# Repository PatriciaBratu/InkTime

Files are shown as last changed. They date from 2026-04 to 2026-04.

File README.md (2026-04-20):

README  
  
┌─────────────────────────────────────────────────────────────┐  
│                        POWER SUPPLY                         │  
│                                                             │  
│  Li-Po Battery (3.7V)                                       │  
│       │                                                     │  
│       ▼                                                     │  
│  BQ25180 (Charger IC)  ◄──── USB Type-C (J4)                │  
│       │                                                     │  
│       ▼                                                     │  
│  RT6160A (Buck-Boost)  ──► 3.3V stable output               │  
│       │                                                     │  
│  MAX17048 (Fuel Gauge) ──► I2C ──► nRF52840                 │  
└─────────────────────────────────────────────────────────────┘  
  
┌─────────────────────────────────────────────────────────────┐  
│                    PROCESSING UNIT                          │  
│                                                             │  
│              nRF52840 (ARM Cortex-M4F)                      │  
│        ┌──────────────┴──────────────┐                      │  
│        │                             │                      │  
│      SPI bus                       I2C bus                  │  
│        │                             │                      │  
│  e-Paper Display               ┌─────┴──────┐               │  
│  (1.54" GDEW0154)              │            │               │  
│                            BMA421       DRV2605YZFR         │  
│                           (Accel.)    (Haptic Driver)       │  
└─────────────────────────────────────────────────────────────┘  

Descrierea Funcționalității Hardware

Sistemul InkTime v6 este optimizat pentru autonomie maximă, utilizând componente de ultimă generație.  
## Microcontroller — nRF52840  
Utilizăm SoC-ul **nRF52840** (U1) care integrează un nucleu ARM Cortex-M4F la 64 MHz. Acesta gestionează stiva **Bluetooth Low Energy (BLE)** și coordonează perifericele prin interfețele SPI și I2C.  
  
Sistemul de Alimentare (Power Tree)  
**BQ25180 (IC1):** IC de încărcare liniară cu managementul căii de alimentare (Power Path).  
**MAX17048 (U3):** Fuel Gauge care utilizează algoritmul ModelGauge pentru monitorizarea precisă a stării de încărcare a bateriei via I2C, fără a necesita calibrare manuală.  
**RT6160A (IC9):** Regulator Buck-Boost care menține o ieșire stabilă de 3.3V pe tot parcursul ciclului de descărcare al bateriei (4.2V - 3.0V).  
  
## Afișaj e-Paper (1.54")  
Utilizăm panoul **GDEW0154** conectat prin J1. Consumul este zero între actualizări. Schema include un **E-Paper Drive Circuit** cu inductorul **L5 (5.6uH)** și diode Schottky **MBR0530** (D2, D4, D5) pentru generarea tensiunilor de refresh. Alimentarea este controlată de un MOSFET P-Channel (Q1) pentru a elimina curentul de scurgere în standby.  
  
Senzor de Mișcare și Haptics  
**BMA421 (IC3):** Accelerometru triaxial ultra-low-power utilizat pentru funcția de *tilt-to-wake* și pedometru.  
**DRV2605YZFR (IC2):** Driver haptic specializat care controlează motorul de vibrații, oferind peste 100 de efecte tactile pre-programate via I2C.  
  
## Configurația Pinilor nRF52840  
Maparea pinilor a fost optimizată pentru rutarea pe 4 straturi a PCB-ului:  
+1  

| Semnal | Pin nRF52 | Direcție | Descriere |
| --- | --- | --- | --- |
| EPD_SCK  | P0.28 | Output | Clock SPI pentru afișaj |
| EPD_MOSI | P0.29 | Output | Date imagine către afișaj  |
| EPD_CS | P0.30 | Output | Chip Select Display |
| EPD_DC | P0.31 | Output | Data/Command selector |
| I2C_SDA  | P0.26 | Bidirecțional | Magistrală date senzori |
| I2C_SCL  | P0.27 | Output | Magistrală clock senzori |
| EPD_PWR  | P0.13 | Output | Control alimentare E-Paper |
| SW_UP | P1.00 | Input | Buton Navigare Sus |
| SW_ENT | P1.01 | Input | Buton Selecție |
| SW_DN | P1.02 | Input | Buton Navigare Jos |

## Calcule Consum Energie (Estimativ)  
* **Deep Sleep (System ON):** ~3.2 μA.  
* **I2C Polling (Senzori):** ~150 μA.  
* **E-Paper Refresh:** ~8 mA (timp de 2 secunde).  
* **Baterie 250 mAh:** Autonomie estimată de **35 zile** (cu 10 refresh-uri/zi și Bluetooth activ).  
## Integrare Mecanică  
Designul a fost validat în Fusion 360 prin analiză de coliziune între baterie și componentele înalte (inductorul L5 și conectorul USB-C). Carcasa WearAwareNewCase oferă o protecție IP67 simbolică.

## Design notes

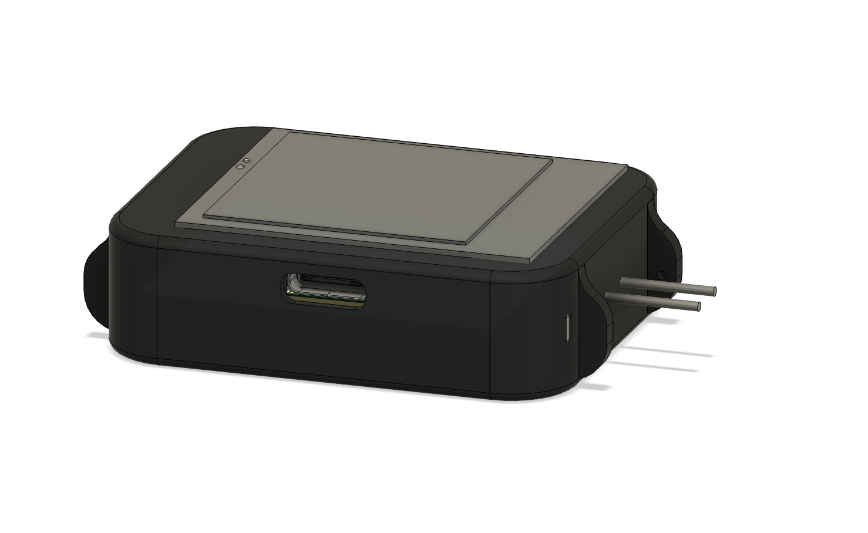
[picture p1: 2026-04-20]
Images/Screenshot 2026-04-20 at 17.06.30.png

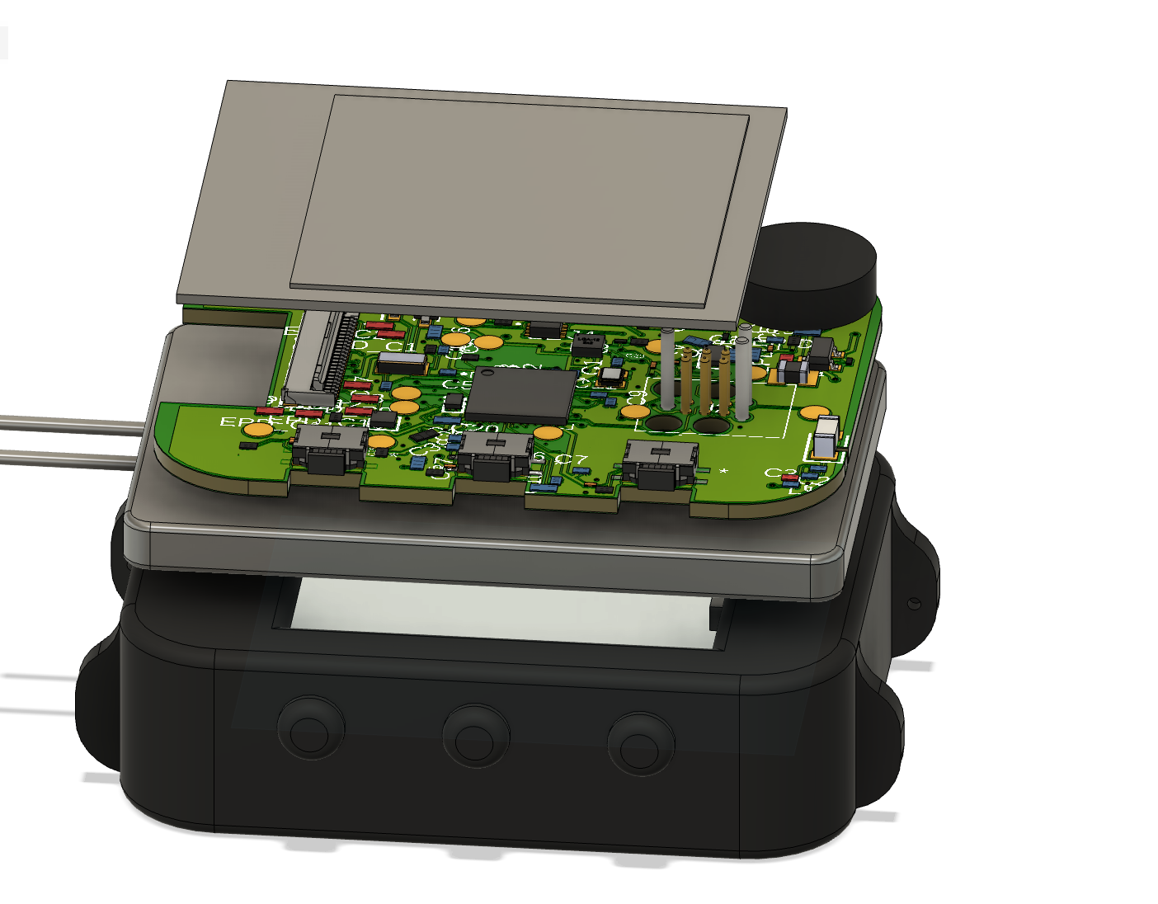
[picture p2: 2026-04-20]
Images/Screenshot 2026-04-20 at 18.16.46.png

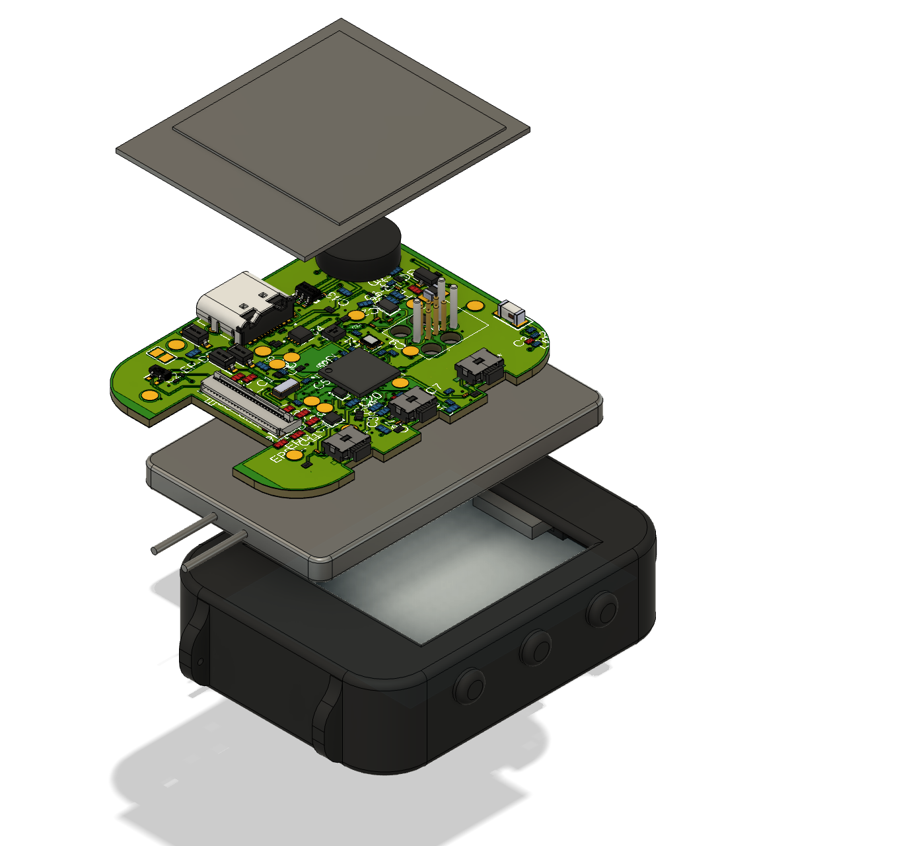
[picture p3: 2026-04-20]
Images/Screenshot 2026-04-20 at 16.59.16.png

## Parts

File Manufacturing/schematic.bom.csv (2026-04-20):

Part | Value | Device | Footprint Name | Detailed Description | ARROW_PART_NUMBER | ARROW_PRICE-STOCK | AVAILABILITY | C23 | C27 | C29 | C30 | C31 | C32 | C34 | C42 | CHECK_PRICES | COPYRIGHT | D | DESCRIPTION | DIGI-KEY_PART_NUMBER_1 | DIGI-KEY_PART_NUMBER_2 | DIGI-KEY_PART_NUMBER_3 | GF | HEIGHT | JLCPCB | MANUFACTURER_NAME | MANUFACTURER_PART_NUMBER | MF | MFR_NAME | MOUSER_PART_NUMBER | MOUSER_PRICE-STOCK | MP | PACKAGE | POPULARITY | PRICE | PROD_ID | PURCHASE-URL | R | R1 | R2 | R3 | R4 | R5 | R7 | R9 | R17 | R18 | SNAPEDA_LINK | TP_SIGNAL_NAME | VALUE
ANT1 | 2450AT18B100E_2450AT18B100E | 2450AT18B100E_2450AT18B100E | 2450AT18B100E_ANTC3216X140N | Antennas 2.45GHz ANTENNA | 2450AT18B100E | https://www.arrow.com/en/products/2450at18b100e/johanson-dielectrics?utm_currency=USD&region=nac |  |  |  |  |  |  |  |  |  |  |  |  | Antennas 2.45GHz ANTENNA |  |  |  |  | 1.4mm |  | JOHANSON TECHNOLOGY | 2450AT18B100E |  |  | 609-2450AT18B100E | https://www.mouser.co.uk/ProductDetail/Johanson-Technology/2450AT18B100E?qs=yCnrNFeXz%252Bh5MFsFIXGZGA%3D%3D
C1 | 12pF | NORDIC_NRF_3_CAPACITOR_0201_L | NORDIC_NRF_3_RESC0201_L | Generic chip capacitor
C1-EP-DR | 10uF | NORDIC_NRF_3_CAPACITOR_0402_L | NORDIC_NRF_3_RESC0402_L | Generic chip capacitor
C2 | 12pF | NORDIC_NRF_3_CAPACITOR_0201_L | NORDIC_NRF_3_RESC0201_L | Generic chip capacitor
C2-EP-DR | 4.7uF/25V | NORDIC_NRF_3_CAPACITOR_0402_L | NORDIC_NRF_3_RESC0402_L | Generic chip capacitor
C3 | 1pF | NORDIC_NRF_3_CAPACITOR_0201_L | NORDIC_NRF_3_RESC0201_L | Generic chip capacitor
C4 | 1pF | NORDIC_NRF_3_CAPACITOR_0201_L | NORDIC_NRF_3_RESC0201_L | Generic chip capacitor
C5 | 100nF | NORDIC_NRF_3_CAPACITOR_0201_L | NORDIC_NRF_3_RESC0201_L | Generic chip capacitor
C6 | 4.7µF | NORDIC_NRF_3_CAPACITOR_0402_L | NORDIC_NRF_3_RESC0402_L | Generic chip capacitor
C7 | 100nF | NORDIC_NRF_3_CAPACITOR_0201_L | NORDIC_NRF_3_RESC0201_L | Generic chip capacitor
C8 | 100nF | NORDIC_NRF_3_CAPACITOR_0201_L | NORDIC_NRF_3_RESC0201_L | Generic chip capacitor
C9 | 820pF | NORDIC_NRF_3_CAPACITOR_0201_L | NORDIC_NRF_3_RESC0201_L | Generic chip capacitor
C10 | N.C. | NORDIC_NRF_3_CAPACITOR_0201_L | NORDIC_NRF_3_RESC0201_L | Generic chip capacitor
C11 | 100pF | NORDIC_NRF_3_CAPACITOR_0201_L | NORDIC_NRF_3_RESC0201_L | Generic chip capacitor
C12 | 100nF | NORDIC_NRF_3_CAPACITOR_0201_L | NORDIC_NRF_3_RESC0201_L | Generic chip capacitor
C13 | N.C. | NORDIC_NRF_3_CAPACITOR_0201_L | NORDIC_NRF_3_RESC0201_L | Generic chip capacitor
C14 | 4.7µF | NORDIC_NRF_3_CAPACITOR_0402_L | NORDIC_NRF_3_RESC0402_L | Generic chip capacitor
C15 | 1.0µF | NORDIC_NRF_3_CAPACITOR_0402_L | NORDIC_NRF_3_RESC0402_L | Generic chip capacitor
C16 | 47nF | NORDIC_NRF_3_CAPACITOR_0201_L | NORDIC_NRF_3_RESC0201_L | Generic chip capacitor
C17 | 12pF | NORDIC_NRF_3_CAPACITOR_0201_L | NORDIC_NRF_3_RESC0201_L | Generic chip capacitor
C18 | 12pF | NORDIC_NRF_3_CAPACITOR_0201_L | NORDIC_NRF_3_RESC0201_L | Generic chip capacitor
C19 | 100nF | NORDIC_NRF_3_CAPACITOR_0201_L | NORDIC_NRF_3_RESC0201_L | Generic chip capacitor
C20 | 4.7µF | NORDIC_NRF_3_CAPACITOR_0402_L | NORDIC_NRF_3_RESC0402_L | Generic chip capacitor
C21 | 4.7µF | NORDIC_NRF_3_CAPACITOR_0402_L | NORDIC_NRF_3_RESC0402_L | Generic chip capacitor
C22 | N.C. | NORDIC_NRF_3_CAPACITOR_0201_L | NORDIC_NRF_3_RESC0201_L | Generic chip capacitor
C23 | GRM011R60J152KE01L_2_GRM011R60J152KE01L | GRM011R60J152KE01L_2_GRM011R60J152KE01L | GRM011R60J152KE01L_2_CAPC0201X13N | Check availability |  |  | In Stock | 0.1uF |  |  |  |  |  |  |  | https://www.snapeda.com/parts/GRM011R60J152KE01L/Murata/view-part/?ref=eda |  |  | SMD Capacitor X5R(EIA) with Capacitance: 1500pF Tol. 10%. Rated Voltage: 6.3Vdc |  |  |  |  |  |  |  |  | Murata |  |  |  | GRM011R60J152KE01L | 0201 Murata |  | None |  |  |  |  |  |  |  |  |  |  |  |  | https://www.snapeda.com/parts/GRM011R60J152KE01L/Murata/view-part/?ref=snap
C24 | 10uF | NORDIC_NRF_3_CAPACITOR_0402_L | NORDIC_NRF_3_RESC0402_L | Generic chip capacitor
C25 | 22uF | NORDIC_NRF_3_CAPACITOR_0402_L | NORDIC_NRF_3_RESC0402_L | Generic chip capacitor
C27 | GRM011R60J152KE01L_2_GRM011R60J152KE01L | GRM011R60J152KE01L_2_GRM011R60J152KE01L | GRM011R60J152KE01L_2_CAPC0201X13N | Check availability |  |  | In Stock |  | 0.1uF |  |  |  |  |  |  | https://www.snapeda.com/parts/GRM011R60J152KE01L/Murata/view-part/?ref=eda |  |  | SMD Capacitor X5R(EIA) with Capacitance: 1500pF Tol. 10%. Rated Voltage: 6.3Vdc |  |  |  |  |  |  |  |  | Murata |  |  |  | GRM011R60J152KE01L | 0201 Murata |  | None |  |  |  |  |  |  |  |  |  |  |  |  | https://www.snapeda.com/parts/GRM011R60J152KE01L/Murata/view-part/?ref=snap
C29 | GRM011R60J152KE01L_2_GRM011R60J152KE01L | GRM011R60J152KE01L_2_GRM011R60J152KE01L | GRM011R60J152KE01L_2_CAPC0201X13N | Check availability |  |  | In Stock |  |  | 1uF |  |  |  |  |  | https://www.snapeda.com/parts/GRM011R60J152KE01L/Murata/view-part/?ref=eda |  |  | SMD Capacitor X5R(EIA) with Capacitance: 1500pF Tol. 10%. Rated Voltage: 6.3Vdc |  |  |  |  |  |  |  |  | Murata |  |  |  | GRM011R60J152KE01L | 0201 Murata |  | None |  |  |  |  |  |  |  |  |  |  |  |  | https://www.snapeda.com/parts/GRM011R60J152KE01L/Murata/view-part/?ref=snap
C30 | GRM011R60J152KE01L_2_GRM011R60J152KE01L | GRM011R60J152KE01L_2_GRM011R60J152KE01L | GRM011R60J152KE01L_2_CAPC0201X13N | Check availability |  |  | In Stock |  |  |  | 1uF |  |  |  |  | https://www.snapeda.com/parts/GRM011R60J152KE01L/Murata/view-part/?ref=eda |  |  | SMD Capacitor X5R(EIA) with Capacitance: 1500pF Tol. 10%. Rated Voltage: 6.3Vdc |  |  |  |  |  |  |  |  | Murata |  |  |  | GRM011R60J152KE01L | 0201 Murata |  | None |  |  |  |  |  |  |  |  |  |  |  |  | https://www.snapeda.com/parts/GRM011R60J152KE01L/Murata/view-part/?ref=snap
C31 | GRM011R60J152KE01L_2_GRM011R60J152KE01L | GRM011R60J152KE01L_2_GRM011R60J152KE01L | GRM011R60J152KE01L_2_CAPC0201X13N | Check availability |  |  | In Stock |  |  |  |  | 1uF |  |  |  | https://www.snapeda.com/parts/GRM011R60J152KE01L/Murata/view-part/?ref=eda |  |  | SMD Capacitor X5R(EIA) with Capacitance: 1500pF Tol. 10%. Rated Voltage: 6.3Vdc |  |  |  |  |  |  |  |  | Murata |  |  |  | GRM011R60J152KE01L | 0201 Murata |  | None |  |  |  |  |  |  |  |  |  |  |  |  | https://www.snapeda.com/parts/GRM011R60J152KE01L/Murata/view-part/?ref=snap
C32 | GRM011R60J152KE01L_2_GRM011R60J152KE01L | GRM011R60J152KE01L_2_GRM011R60J152KE01L | GRM011R60J152KE01L_2_CAPC0201X13N | Check availability |  |  | In Stock |  |  |  |  |  | 1uF |  |  | https://www.snapeda.com/parts/GRM011R60J152KE01L/Murata/view-part/?ref=eda |  |  | SMD Capacitor X5R(EIA) with Capacitance: 1500pF Tol. 10%. Rated Voltage: 6.3Vdc |  |  |  |  |  |  |  |  | Murata |  |  |  | GRM011R60J152KE01L | 0201 Murata |  | None |  |  |  |  |  |  |  |  |  |  |  |  | https://www.snapeda.com/parts/GRM011R60J152KE01L/Murata/view-part/?ref=snap
C33 | 22uF | NORDIC_NRF_3_CAPACITOR_0402_L | NORDIC_NRF_3_RESC0402_L | Generic chip capacitor
C34 | GRM011R60J152KE01L_2_GRM011R60J152KE01L | GRM011R60J152KE01L_2_GRM011R60J152KE01L | GRM011R60J152KE01L_2_CAPC0201X13N | Check availability |  |  | In Stock |  |  |  |  |  |  | 0.1uF |  | https://www.snapeda.com/parts/GRM011R60J152KE01L/Murata/view-part/?ref=eda |  |  | SMD Capacitor X5R(EIA) with Capacitance: 1500pF Tol. 10%. Rated Voltage: 6.3Vdc |  |  |  |  |  |  |  |  | Murata |  |  |  | GRM011R60J152KE01L | 0201 Murata |  | None |  |  |  |  |  |  |  |  |  |  |  |  | https://www.snapeda.com/parts/GRM011R60J152KE01L/Murata/view-part/?ref=snap
C37 |  | NORDIC_NRF_3_CAPACITOR_0402_L | NORDIC_NRF_3_RESC0402_L | Generic chip capacitor |  |  |  |  |  |  |  |  |  |  |  |  |  |  |  |  |  |  | 1uF
C38 | GRM011R60J152KE01L_2_GRM011R60J152KE01L | GRM011R60J152KE01L_2_GRM011R60J152KE01L | GRM011R60J152KE01L_2_CAPC0201X13N | Check availability |  |  | In Stock |  |  |  |  |  |  |  |  | https://www.snapeda.com/parts/GRM011R60J152KE01L/Murata/view-part/?ref=eda |  | 1uF | SMD Capacitor X5R(EIA) with Capacitance: 1500pF Tol. 10%. Rated Voltage: 6.3Vdc |  |  |  |  |  |  |  |  | Murata |  |  |  | GRM011R60J152KE01L | 0201 Murata |  | None |  |  |  |  |  |  |  |  |  |  |  |  | https://www.snapeda.com/parts/GRM011R60J152KE01L/Murata/view-part/?ref=snap
C39 | 10uF | NORDIC_NRF_3_CAPACITOR_0402_L | NORDIC_NRF_3_RESC0402_L | Generic chip capacitor
C42 | GRM011R60J152KE01L_2_GRM011R60J152KE01L | GRM011R60J152KE01L_2_GRM011R60J152KE01L | GRM011R60J152KE01L_2_CAPC0201X13N | Check availability |  |  | In Stock |  |  |  |  |  |  |  | 0.1uF | https://www.snapeda.com/parts/GRM011R60J152KE01L/Murata/view-part/?ref=eda |  |  | SMD Capacitor X5R(EIA) with Capacitance: 1500pF Tol. 10%. Rated Voltage: 6.3Vdc |  |  |  |  |  |  |  |  | Murata |  |  |  | GRM011R60J152KE01L | 0201 Murata |  | None |  |  |  |  |  |  |  |  |  |  |  |  | https://www.snapeda.com/parts/GRM011R60J152KE01L/Murata/view-part/?ref=snap
C43 | 4.7uF | NORDIC_NRF_3_CAPACITOR_0402_L | NORDIC_NRF_3_RESC0402_L | Generic chip capacitor
D2 | ESP32_C6_LIBRARY_5_MBR0530 | ESP32_C6_LIBRARY_5_MBR0530 | ESP32_C6_LIBRARY_5_SOD3716X135N | ON SEMICONDUCTOR - MBR0530 - DIODE, SCHOTTKY, 0.5A, 30V, SOD-123 |  |  | In Stock |  |  |  |  |  |  |  |  | https://www.snapeda.com/parts/MBR0530/Onsemi/view-part/?ref=eda |  |  | Diode Schottky 30 V 500mA Surface Mount SOD-123 |  |  |  |  |  |  |  |  | ON Semiconductor |  |  |  | MBR0530 | SOD-123-2 ON Semiconductor |  | None |  | https://www.snapeda.com/api/url_track_click_mouser/?unipart_id=179458&manufacturer=ON Semiconductor&part_name=MBR0530&search_term=None |  |  |  |  |  |  |  |  |  |  | https://www.snapeda.com/parts/MBR0530/Onsemi/view-part/?ref=snap
D3 | ESP32_C6_LIBRARY_3_USBLC6-2SC6Y | ESP32_C6_LIBRARY_3_USBLC6-2SC6Y | ESP32_C6_LIBRARY_3_SOT95P280X145-6N | Low Cap. ESD Protection Auto SOT-23-6 STMicroelectronics USBLC6-2SC6Y, Dual Uni-Directional TVS Diode Array, 6-Pin SOT-23 |  |  | In Stock |  |  |  |  |  |  |  |  | https://www.snapeda.com/parts/USBLC6-2SC6Y/STMicroelectronics/view-part/?ref=eda |  |  | 17V Clamp 5A (8/20µs) Ipp Tvs Diode Surface Mount SOT-23-6 |  |  |  |  |  |  |  |  | STMicroelectronics |  |  |  | USBLC6-2SC6Y | SOT-23-6 STMicroelectronics |  | None |  |  |  |  |  |  |  |  |  |  |  |  | https://www.snapeda.com/parts/USBLC6-2SC6Y/STMicroelectronics/view-part/?ref=snap
D4 | ESP32_C6_LIBRARY_5_MBR0530 | ESP32_C6_LIBRARY_5_MBR0530 | ESP32_C6_LIBRARY_5_SOD3716X135N | ON SEMICONDUCTOR - MBR0530 - DIODE, SCHOTTKY, 0.5A, 30V, SOD-123 |  |  | In Stock |  |  |  |  |  |  |  |  | https://www.snapeda.com/parts/MBR0530/Onsemi/view-part/?ref=eda |  |  | Diode Schottky 30 V 500mA Surface Mount SOD-123 |  |  |  |  |  |  |  |  | ON Semiconductor |  |  |  | MBR0530 | SOD-123-2 ON Semiconductor |  | None |  | https://www.snapeda.com/api/url_track_click_mouser/?unipart_id=179458&manufacturer=ON Semiconductor&part_name=MBR0530&search_term=None |  |  |  |  |  |  |  |  |  |  | https://www.snapeda.com/parts/MBR0530/Onsemi/view-part/?ref=snap
D5 | ESP32_C6_LIBRARY_5_MBR0530 | ESP32_C6_LIBRARY_5_MBR0530 | ESP32_C6_LIBRARY_5_SOD3716X135N | ON SEMICONDUCTOR - MBR0530 - DIODE, SCHOTTKY, 0.5A, 30V, SOD-123 |  |  | In Stock |  |  |  |  |  |  |  |  | https://www.snapeda.com/parts/MBR0530/Onsemi/view-part/?ref=eda |  |  | Diode Schottky 30 V 500mA Surface Mount SOD-123 |  |  |  |  |  |  |  |  | ON Semiconductor |  |  |  | MBR0530 | SOD-123-2 ON Semiconductor |  | None |  | https://www.snapeda.com/api/url_track_click_mouser/?unipart_id=179458&manufacturer=ON Semiconductor&part_name=MBR0530&search_term=None |  |  |  |  |  |  |  |  |  |  | https://www.snapeda.com/parts/MBR0530/Onsemi/view-part/?ref=snap
EPD_C1 | 1uF/50V | NORDIC_NRF_3_CAPACITOR_0402_L | NORDIC_NRF_3_RESC0402_L | Generic chip capacitor
EPD_C2 | 1uF/50V | NORDIC_NRF_3_CAPACITOR_0402_L | NORDIC_NRF_3_RESC0402_L | Generic chip capacitor
EPD_C5 | 0.1uF/50V | NORDIC_NRF_3_CAPACITOR_0402_L | NORDIC_NRF_3_RESC0402_L | Generic chip capacitor
EPD_C6 | 1uF/50V | NORDIC_NRF_3_CAPACITOR_0402_L | NORDIC_NRF_3_RESC0402_L | Generic chip capacitor
EPD_C7 | 1uF/50V | NORDIC_NRF_3_CAPACITOR_0402_L | NORDIC_NRF_3_RESC0402_L | Generic chip capacitor
EPD_C8 | 1uF/50V | NORDIC_NRF_3_CAPACITOR_0402_L | NORDIC_NRF_3_RESC0402_L | Generic chip capacitor
EPD_C9 | 1uF/50V | NORDIC_NRF_3_CAPACITOR_0402_L | NORDIC_NRF_3_RESC0402_L | Generic chip capacitor
EPD_C10 | 1uF/50V | NORDIC_NRF_3_CAPACITOR_0402_L | NORDIC_NRF_3_RESC0402_L | Generic chip capacitor
EPD_C11 | 1uF/50V | NORDIC_NRF_3_CAPACITOR_0402_L | NORDIC_NRF_3_RESC0402_L | Generic chip capacitor
EPD_C12 | 1uF/50V | NORDIC_NRF_3_CAPACITOR_0402_L | NORDIC_NRF_3_RESC0402_L | Generic chip capacitor
IC1 | BQ25180YBGR_BQ25180YBGR | BQ25180YBGR_BQ25180YBGR | BQ25180YBGR_BGA8C40P2X4_100X155X50 | Charger IC Lithium Ion/Polymer, Lithium Iron Phosphate 8-DSBGA (1.6x1.1) | BQ25180YBGR | https://www.arrow.com/en/products/bq25180ybgr/texas-instruments?utm_currency=USD&region=nac |  |  |  |  |  |  |  |  |  |  |  |  | Charger IC Lithium Ion/Polymer, Lithium Iron Phosphate 8-DSBGA (1.6x1.1) |  |  |  |  | 0.5mm |  | Texas Instruments | BQ25180YBGR |  |  | 595-BQ25180YBGR | https://www.mouser.co.uk/ProductDetail/Texas-Instruments/BQ25180YBGR?qs=doiCPypUmgEWjAK%252BJAX6Tw%3D%3D
IC2 | DRV2605YZFR_DRV2605YZFR | DRV2605YZFR_DRV2605YZFR | DRV2605YZFR_BGA9C50P3X3_144X144X62 | Haptic Driver for ERM/LRA with Built-In Library and Smart Loop Architecture | DRV2605YZFR | https://www.arrow.com/en/products/drv2605yzfr/texas-instruments?region=nac |  |  |  |  |  |  |  |  |  |  |  |  | Haptic Driver for ERM/LRA with Built-In Library and Smart Loop Architecture |  |  |  |  | 0.625mm |  | Texas Instruments | DRV2605YZFR
IC3 | BMA423_BMA423 | BMA423_BMA423 | BMA423_BMA423 | Accelerometers Triaxial low-g 12bit Acceleration Sensor | BMA423 | https://www.arrow.com/en/products/bma423/bosch |  |  |  |  |  |  |  |  |  |  |  |  | Accelerometers Triaxial low-g 12bit Acceleration Sensor |  |  |  |  | 1mm |  | BOSCH | BMA423 |  |  | 262-BMA423 | https://www.mouser.co.uk/ProductDetail/Bosch-Sensortec/BMA423?qs=HXFqYaX1Q2xC%252BSgeGoX3mg%3D%3D
IC9 | RT6160AWSC_RT6160AWSC | RT6160AWSC_RT6160AWSC | RT6160AWSC_BGA15C40P3X5_140X230X60 | Buck-Boost Regulator Positive Output Step-Up/Step-Down I2C DC-DC Controller IC 15-WL-CSP (BSC) (1.4x2.3) |  |  |  |  |  |  |  |  |  |  |  |  |  |  | Buck-Boost Regulator Positive Output Step-Up/Step-Down I2C DC-DC Controller IC 15-WL-CSP (BSC) (1.4x2.3) |  |  |  |  | 0.6mm |  | RICHTEK | RT6160AWSC |  |  | 835-RT6160AWSC | https://www.mouser.co.uk/ProductDetail/Richtek/RT6160AWSC?qs=amGC7iS6iy%2FLd9PSoixZXQ%3D%3D
J1 | 503480-2400_503480-2400 | 503480-2400_503480-2400 | 503480-2400_5034802400 | FFC & FPC Connectors 0.5mm FPC RA SMT Dual Contact 24Ckt |  |  |  |  |  |  |  |  |  |  |  |  |  |  | FFC & FPC Connectors 0.5mm FPC RA SMT Dual Contact 24Ckt |  |  |  |  | 1.87mm |  | Molex | 503480-2400 |  |  | 538-503480-2400 | https://www.mouser.co.uk/ProductDetail/Molex/503480-2400?qs=OAhjpuo3Vu7efIoxFh9AOw%3D%3D
J2 | TC2030-IDC_TC2030-IDC | TC2030-IDC_TC2030-IDC | TC2030-IDC_TC2030IDC | CABLE ADAPTER 6 POS |  |  |  |  |  |  |  |  |  |  |  |  |  |  | CABLE ADAPTER 6 POS |  |  |  |  | 19mm |  | Tag Connect | TC2030-IDC
J4 | KH-TYPE-C-16P_KH-TYPE-C-16P | KH-TYPE-C-16P_KH-TYPE-C-16P | KH-TYPE-C-16P_KINGHELM_KH-TYPE-C-16P | Check availability |  |  | Not in stock |  |  |  |  |  |  |  |  | https://www.snapeda.com/parts/KH-TYPE-C-16P/Kinghelm/view-part/?ref=eda |  |  |  |  |  |  |  |  |  |  |  | kinghelm |  |  |  | KH-TYPE-C-16P | None |  | None |  |  |  |  |  |  |  |  |  |  |  |  | https://www.snapeda.com/parts/KH-TYPE-C-16P/Kinghelm/view-part/?ref=snap
L1 | 3.9nH | NORDIC_NRF_2_INDUCTOR_0201_L | NORDIC_NRF_2_RESC0201_L | Generic chip inductor
L2 | 10µH | NORDIC_NRF_2_INDUCTOR_0201_L | NORDIC_NRF_2_RESC0201_L | Generic chip inductor
L3 | 15nH | NORDIC_NRF_2_INDUCTOR_0201_L | NORDIC_NRF_2_RESC0201_L | Generic chip inductor
L5 | 10uH | ESP32_C6_LIBRARY_2_744043680IND_4828-WE-TPC_WRE | ESP32_C6_LIBRARY_2_IND_4828-WE-TPC_WRE |  |  |  |  |  |  |  |  |  |  |  |  |  | Copyright (C) 2024 Ultra Librarian. All rights reserved. |  |  |  |  |  |  |  |  |  | 744043680 |  | Wurth Electronics
L7 | MLP2016SR47MT0S1_FTC252012SR47MBCA | MLP2016SR47MT0S1_FTC252012SR47MBCA | MLP2016SR47MT0S1_INDC2016X100N | SMD / SMT Inductors (Coils), L=0.47?H, L x W x T : |  |  |  |  |  |  |  |  |  |  |  |  |  |  | SMD / SMT Inductors (Coils), L=0.47?H, L x W x T : |  |  |  |  | 1mm | https://jlcpcb.com/partdetail/6763488-FTC252012SR47MBCA/C5832368 | TDK | FTC252012SR47MBCA
Q1 | 20V/4.2A/52mΩ/1.4W | ESP32_C6_LIBRARY_4_ESP32_WROVER_SPARKFUN-DISCRETESEMI_MOSFET_PCH-DMG2305UX-7 | ESP32_C6_LIBRARY_4_ESP32_C6_LIBRARY_4_ESP32_C6_LIBRARY_4_ESP32_C6_LIBRARY_4_ESP32_WROVER_SPARKFUN-DISCRETESEMI_SOT23-3 | P-channel MOSFETs |  |  |  |  |  |  |  |  |  |  |  |  |  |  |  |  |  |  |  |  |  |  |  |  |  |  |  |  |  |  |  | TRAN-14388 |  |  |  |  |  |  |  |  |  |  |  |  |  | 20V/4.2A/52mΩ/1.4W
Q3 | ESP32_C6_LIBRARY_6_SI1308EDL-T1-GE3 | ESP32_C6_LIBRARY_6_SI1308EDL-T1-GE3 | ESP32_C6_LIBRARY_6_SOT65P210X110-3N | MOSFET N-Ch 30V 1.5A TrenchFET SC70 Vishay Si1308EDL-T1-GE3 N-channel MOSFET Transistor, 1.5 A, 30 V, 3-Pin SC-70 |  |  | In Stock |  |  |  |  |  |  |  |  | https://www.snapeda.com/parts/SI1308EDL-T1-GE3/Vishay+Siliconix/view-part/?ref=eda |  |  | Si1308EDL-T1-GE3 N-channel MOSFET Transistor, 1.5 A, 30 V, 3-Pin SC-70 | Siliconix / Vishay SI1308EDL-T1-GE3 |  |  |  |  |  |  |  |  | Vishay Siliconix |  |  |  | SI1308EDL-T1-GE3 | SOT-323 Vishay Semiconductor |  | None |  | https://www.snapeda.com/api/url_track_click_mouser/?unipart_id=274603&manufacturer=Vishay Siliconix&part_name=SI1308EDL-T1-GE3&search_term=None |  |  |  |  |  |  |  |  |  |  | https://www.snapeda.com/parts/SI1308EDL-T1-GE3/Vishay+Siliconix/view-part/?ref=snap
R1_EP_DR | ERA-1AEB3401C_CPF0201D7K68C1 | ERA-1AEB3401C_CPF0201D7K68C1 | ERA-1AEB3401C_0201 | 7.68k 0201 Thin Film Surface Mount Fixed Resistor +/-0.5% 0.031W CPF0201D7K68C1 |  |  |  |  |  |  |  |  |  |  |  |  |  |  |  |  |  |  |  |  |  |  |  |  |  |  |  |  |  |  |  |  |  | 0.47
R1_USB | ERA-1AEB3401C_CPF0201D7K68C1 | ERA-1AEB3401C_CPF0201D7K68C1 | ERA-1AEB3401C_0201 | 7.68k 0201 Thin Film Surface Mount Fixed Resistor +/-0.5% 0.031W CPF0201D7K68C1 |  |  |  |  |  |  |  |  |  |  |  |  |  |  |  |  |  |  |  |  |  |  |  |  |  |  |  |  |  |  |  |  |  |  | 5k1
R2 | CPF0201D7K68C1_CPF0201D7K68C1 | CPF0201D7K68C1_CPF0201D7K68C1 | CPF0201D7K68C1_0201 | 7.68k 0201 Thin Film Surface Mount Fixed Resistor +/-0.5% 0.031W CPF0201D7K68C1 |  |  |  |  |  |  |  |  |  |  |  |  |  |  |  |  |  |  |  |  |  |  |  |  |  |  |  |  |  |  |  |  |  |  |  | 0
R2_EP_DR | ERA-1AEB3401C_CPF0201D7K68C1 | ERA-1AEB3401C_CPF0201D7K68C1 | ERA-1AEB3401C_0201 | 7.68k 0201 Thin Film Surface Mount Fixed Resistor +/-0.5% 0.031W CPF0201D7K68C1 |  |  |  |  |  |  |  |  |  |  |  |  |  |  |  |  |  |  |  |  |  |  |  |  |  |  |  |  |  |  |  |  |  | 10K
R2_USB | ERA-1AEB3401C_CPF0201D7K68C1 | ERA-1AEB3401C_CPF0201D7K68C1 | ERA-1AEB3401C_0201 | 7.68k 0201 Thin Film Surface Mount Fixed Resistor +/-0.5% 0.031W CPF0201D7K68C1 |  |  |  |  |  |  |  |  |  |  |  |  |  |  |  |  |  |  |  |  |  |  |  |  |  |  |  |  |  |  |  |  |  |  |  | 5k1
R3 | ERA-1AEB3401C_CPF0201D7K68C1 | ERA-1AEB3401C_CPF0201D7K68C1 | ERA-1AEB3401C_0201 | 7.68k 0201 Thin Film Surface Mount Fixed Resistor +/-0.5% 0.031W CPF0201D7K68C1 |  |  |  |  |  |  |  |  |  |  |  |  |  |  |  |  |  |  |  |  |  |  |  |  |  |  |  |  |  |  |  |  |  |  |  |  | 0
R4 | CPF0201D7K68C1_CPF0201D7K68C1 | CPF0201D7K68C1_CPF0201D7K68C1 | CPF0201D7K68C1_0201 | 7.68k 0201 Thin Film Surface Mount Fixed Resistor +/-0.5% 0.031W CPF0201D7K68C1 |  |  |  |  |  |  |  |  |  |  |  |  |  |  |  |  |  |  |  |  |  |  |  |  |  |  |  |  |  |  |  |  |  |  |  |  |  | 0
R5 | CPF0201D7K68C1_CPF0201D7K68C1 | CPF0201D7K68C1_CPF0201D7K68C1 | CPF0201D7K68C1_0201 | 7.68k 0201 Thin Film Surface Mount Fixed Resistor +/-0.5% 0.031W CPF0201D7K68C1 |  |  |  |  |  |  |  |  |  |  |  |  |  |  |  |  |  |  |  |  |  |  |  |  |  |  |  |  |  |  |  |  |  |  |  |  |  |  | 10k
R7 | CPF0201D7K68C1_CPF0201D7K68C1 | CPF0201D7K68C1_CPF0201D7K68C1 | CPF0201D7K68C1_0201 | 7.68k 0201 Thin Film Surface Mount Fixed Resistor +/-0.5% 0.031W CPF0201D7K68C1 |  |  |  |  |  |  |  |  |  |  |  |  |  |  |  |  |  |  |  |  |  |  |  |  |  |  |  |  |  |  |  |  |  |  |  |  |  |  |  | 10k
R8 | CPF0201D7K68C1_CPF0201D7K68C1 | CPF0201D7K68C1_CPF0201D7K68C1 | CPF0201D7K68C1_0201 | 7.68k 0201 Thin Film Surface Mount Fixed Resistor +/-0.5% 0.031W CPF0201D7K68C1 |  |  |  |  |  |  |  |  |  |  |  |  |  |  |  |  |  |  |  |  |  |  |  |  |  |  |  |  |  |  |  |  |  |  |  |  |  |  |  | 10k
R9 | 10k | CPF0201D7K68C1_CPF0201D7K68C1 | CPF0201D7K68C1_0201 | 7.68k 0201 Thin Film Surface Mount Fixed Resistor +/-0.5% 0.031W CPF0201D7K68C1 |  |  |  |  |  |  |  |  |  |  |  |  |  |  |  |  |  |  |  |  |  |  |  |  |  |  |  |  |  |  |  |  |  | 10K
R17 | CPF0201D7K68C1_CPF0201D7K68C1 | CPF0201D7K68C1_CPF0201D7K68C1 | CPF0201D7K68C1_0201 | 7.68k 0201 Thin Film Surface Mount Fixed Resistor +/-0.5% 0.031W CPF0201D7K68C1 |  |  |  |  |  |  |  |  |  |  |  |  |  |  |  |  |  |  |  |  |  |  |  |  |  |  |  |  |  |  |  |  |  |  |  |  |  |  |  |  |  | 3K3
R18 | CPF0201D7K68C1_CPF0201D7K68C1 | CPF0201D7K68C1_CPF0201D7K68C1 | CPF0201D7K68C1_0201 | 7.68k 0201 Thin Film Surface Mount Fixed Resistor +/-0.5% 0.031W CPF0201D7K68C1 |  |  |  |  |  |  |  |  |  |  |  |  |  |  |  |  |  |  |  |  |  |  |  |  |  |  |  |  |  |  |  |  |  |  |  |  |  |  |  |  |  |  | 3K3
R_PWR_EPD | ERA-1AEB3401C_CPF0201D7K68C1 | ERA-1AEB3401C_CPF0201D7K68C1 | ERA-1AEB3401C_0201 | 7.68k 0201 Thin Film Surface Mount Fixed Resistor +/-0.5% 0.031W CPF0201D7K68C1 |  |  |  |  |  |  |  |  |  |  |  |  |  |  |  |  |  |  |  |  |  |  |  |  |  |  |  |  |  |  |  |  |  | 10K
R_TYPE_SEL | ERA-1AEB3401C_CPF0201D7K68C1 | ERA-1AEB3401C_CPF0201D7K68C1 | ERA-1AEB3401C_0201 | 7.68k 0201 Thin Film Surface Mount Fixed Resistor +/-0.5% 0.031W CPF0201D7K68C1 |  |  |  |  |  |  |  |  |  |  |  |  |  |  |  |  |  |  |  |  |  |  |  |  |  |  |  |  |  |  |  |  |  | 2.2
SCL | NORDIC_NRF_4_NRF52840_QF | NORDIC_NRF_4_NRF52840_QF | NORDIC_NRF_4_AQFN50P700X700X85_HS-74N | nRF52840
SJ1 |  | ESP32_C6_LIBRARY_7_JUMPER_SJ | ESP32_C6_LIBRARY_7_JUMPER_SJ | SMD solder JUMPER |  |  |  |  |  |  |  |  |  |  |  |  |  |  |  |  |  |  |  |  |  |  |  |  |  |  |  |  |  | 3
SW_DN | 2025-10-22_07-23-44_LIBRARY_EVP-AKE31ASW_EVP-AKE31A_PAN | 2025-10-22_07-23-44_LIBRARY_EVP-AKE31ASW_EVP-AKE31A_PAN | 2025-10-22_07-23-44_LIBRARY_SW_EVP-AKE31A_PAN |  |  |  |  |  |  |  |  |  |  |  |  |  | Copyright (C) 2025 Ultra Librarian. All rights reserved. |  |  | P123437TR-ND | P123437CT-ND | P123437DKR-ND |  |  |  | Panasonic | EVP-AKE31A
SW_ENT | 2025-10-22_07-23-44_LIBRARY_EVP-AKE31ASW_EVP-AKE31A_PAN | 2025-10-22_07-23-44_LIBRARY_EVP-AKE31ASW_EVP-AKE31A_PAN | 2025-10-22_07-23-44_LIBRARY_SW_EVP-AKE31A_PAN |  |  |  |  |  |  |  |  |  |  |  |  |  | Copyright (C) 2025 Ultra Librarian. All rights reserved. |  |  | P123437TR-ND | P123437CT-ND | P123437DKR-ND |  |  |  | Panasonic | EVP-AKE31A
SW_UP | 2025-10-22_07-23-44_LIBRARY_EVP-AKE31ASW_EVP-AKE31A_PAN | 2025-10-22_07-23-44_LIBRARY_EVP-AKE31ASW_EVP-AKE31A_PAN | 2025-10-22_07-23-44_LIBRARY_SW_EVP-AKE31A_PAN |  |  |  |  |  |  |  |  |  |  |  |  |  | Copyright (C) 2025 Ultra Librarian. All rights reserved. |  |  | P123437TR-ND | P123437CT-ND | P123437DKR-ND |  |  |  | Panasonic | EVP-AKE31A
TP_3.3V | HECTOR_WATCH_1_TPTP20R | HECTOR_WATCH_1_TPTP20R | HECTOR_WATCH_1_TP20R | Test pad |  |  |  |  |  |  |  |  |  |  |  |  |  |  |  |  |  |  |  |  |  |  |  |  |  |  |  |  |  | 2
TP_3V3 | HECTOR_WATCH_1_TPTP20R | HECTOR_WATCH_1_TPTP20R | HECTOR_WATCH_1_TP20R | Test pad |  |  |  |  |  |  |  |  |  |  |  |  |  |  |  |  |  |  |  |  |  |  |  |  |  |  |  |  |  | 2
TP_BAT_GND | HECTOR_WATCH_1_TPTP20R | HECTOR_WATCH_1_TPTP20R | HECTOR_WATCH_1_TP20R | Test pad |  |  |  |  |  |  |  |  |  |  |  |  |  |  |  |  |  |  |  |  |  |  |  |  |  |  |  |  |  | 2
TP_GND | HECTOR_WATCH_1_TPTP20R | HECTOR_WATCH_1_TPTP20R | HECTOR_WATCH_1_TP20R | Test pad |  |  |  |  |  |  |  |  |  |  |  |  |  |  |  |  |  |  |  |  |  |  |  |  |  |  |  |  |  | 2
TP_ON | HECTOR_WATCH_1_TPTP20R | HECTOR_WATCH_1_TPTP20R | HECTOR_WATCH_1_TP20R | Test pad |  |  |  |  |  |  |  |  |  |  |  |  |  |  |  |  |  |  |  |  |  |  |  |  |  |  |  |  |  | 2
TP_OP | HECTOR_WATCH_1_TPTP20R | HECTOR_WATCH_1_TPTP20R | HECTOR_WATCH_1_TP20R | Test pad |  |  |  |  |  |  |  |  |  |  |  |  |  |  |  |  |  |  |  |  |  |  |  |  |  |  |  |  |  | 2
TP_RESET | HECTOR_WATCH_1_TPTP20R | HECTOR_WATCH_1_TPTP20R | HECTOR_WATCH_1_TP20R | Test pad |  |  |  |  |  |  |  |  |  |  |  |  |  |  |  |  |  |  |  |  |  |  |  |  |  |  |  |  |  | 2
TP_SCL | HECTOR_WATCH_1_TPTP20R | HECTOR_WATCH_1_TPTP20R | HECTOR_WATCH_1_TP20R | Test pad |  |  |  |  |  |  |  |  |  |  |  |  |  |  |  |  |  |  |  |  |  |  |  |  |  |  |  |  |  | 2
TP_SDA | HECTOR_WATCH_1_TPTP20R | HECTOR_WATCH_1_TPTP20R | HECTOR_WATCH_1_TP20R | Test pad |  |  |  |  |  |  |  |  |  |  |  |  |  |  |  |  |  |  |  |  |  |  |  |  |  |  |  |  |  | 2
TP_SWDCLK | HECTOR_WATCH_1_TPTP20R | HECTOR_WATCH_1_TPTP20R | HECTOR_WATCH_1_TP20R | Test pad |  |  |  |  |  |  |  |  |  |  |  |  |  |  |  |  |  |  |  |  |  |  |  |  |  |  |  |  |  | 2
TP_SWDIO | HECTOR_WATCH_1_TPTP20R | HECTOR_WATCH_1_TPTP20R | HECTOR_WATCH_1_TP20R | Test pad |  |  |  |  |  |  |  |  |  |  |  |  |  |  |  |  |  |  |  |  |  |  |  |  |  |  |  |  |  | 2
TP_SWO | HECTOR_WATCH_1_TPTP20R | HECTOR_WATCH_1_TPTP20R | HECTOR_WATCH_1_TP20R | Test pad |  |  |  |  |  |  |  |  |  |  |  |  |  |  |  |  |  |  |  |  |  |  |  |  |  |  |  |  |  | 2
TP_VBAT | HECTOR_WATCH_1_TPTP20R | HECTOR_WATCH_1_TPTP20R | HECTOR_WATCH_1_TP20R | Test pad |  |  |  |  |  |  |  |  |  |  |  |  |  |  |  |  |  |  |  |  |  |  |  |  |  |  |  |  |  | 2
TP_VREG | HECTOR_WATCH_1_TPTP20R | HECTOR_WATCH_1_TPTP20R | HECTOR_WATCH_1_TP20R | Test pad |  |  |  |  |  |  |  |  |  |  |  |  |  |  |  |  |  |  |  |  |  |  |  |  |  |  |  |  |  | 2
U3 | ESP32_C6_LIBRARY_MAX17048G+T10 | ESP32_C6_LIBRARY_MAX17048G+T10 | ESP32_C6_LIBRARY_SON50P200X200X80-9N | Check availability |  |  | In Stock |  |  |  |  |  |  |  |  | https://www.snapeda.com/parts/MAX17048G+T10/Analog+Devices/view-part/?ref=eda |  |  | 3µA 1-Cell/2-Cell Fuel Gauge with ModelGauge |  |  |  |  |  |  |  |  | Analog Devices |  |  |  | MAX17048G+T10 | TDFN-8 Maxim |  | None |  | https://www.snapeda.com/api/url_track_click_mouser/?unipart_id=329239&manufacturer=Analog Devices&part_name=MAX17048G+T10&search_term=None |  |  |  |  |  |  |  |  |  |  | https://www.snapeda.com/parts/MAX17048G+T10/Analog+Devices/view-part/?ref=snap
X1 | 32MHz | NORDIC_NRF_XTAL_32MHZ | NORDIC_NRF_BT-XTAL_2016_N
X2 | 32.768kHz | NORDIC_NRF_1_XTAL_32KHZ | NORDIC_NRF_1_XTAL_3215_N

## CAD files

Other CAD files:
Mechanical/Watch.f3z

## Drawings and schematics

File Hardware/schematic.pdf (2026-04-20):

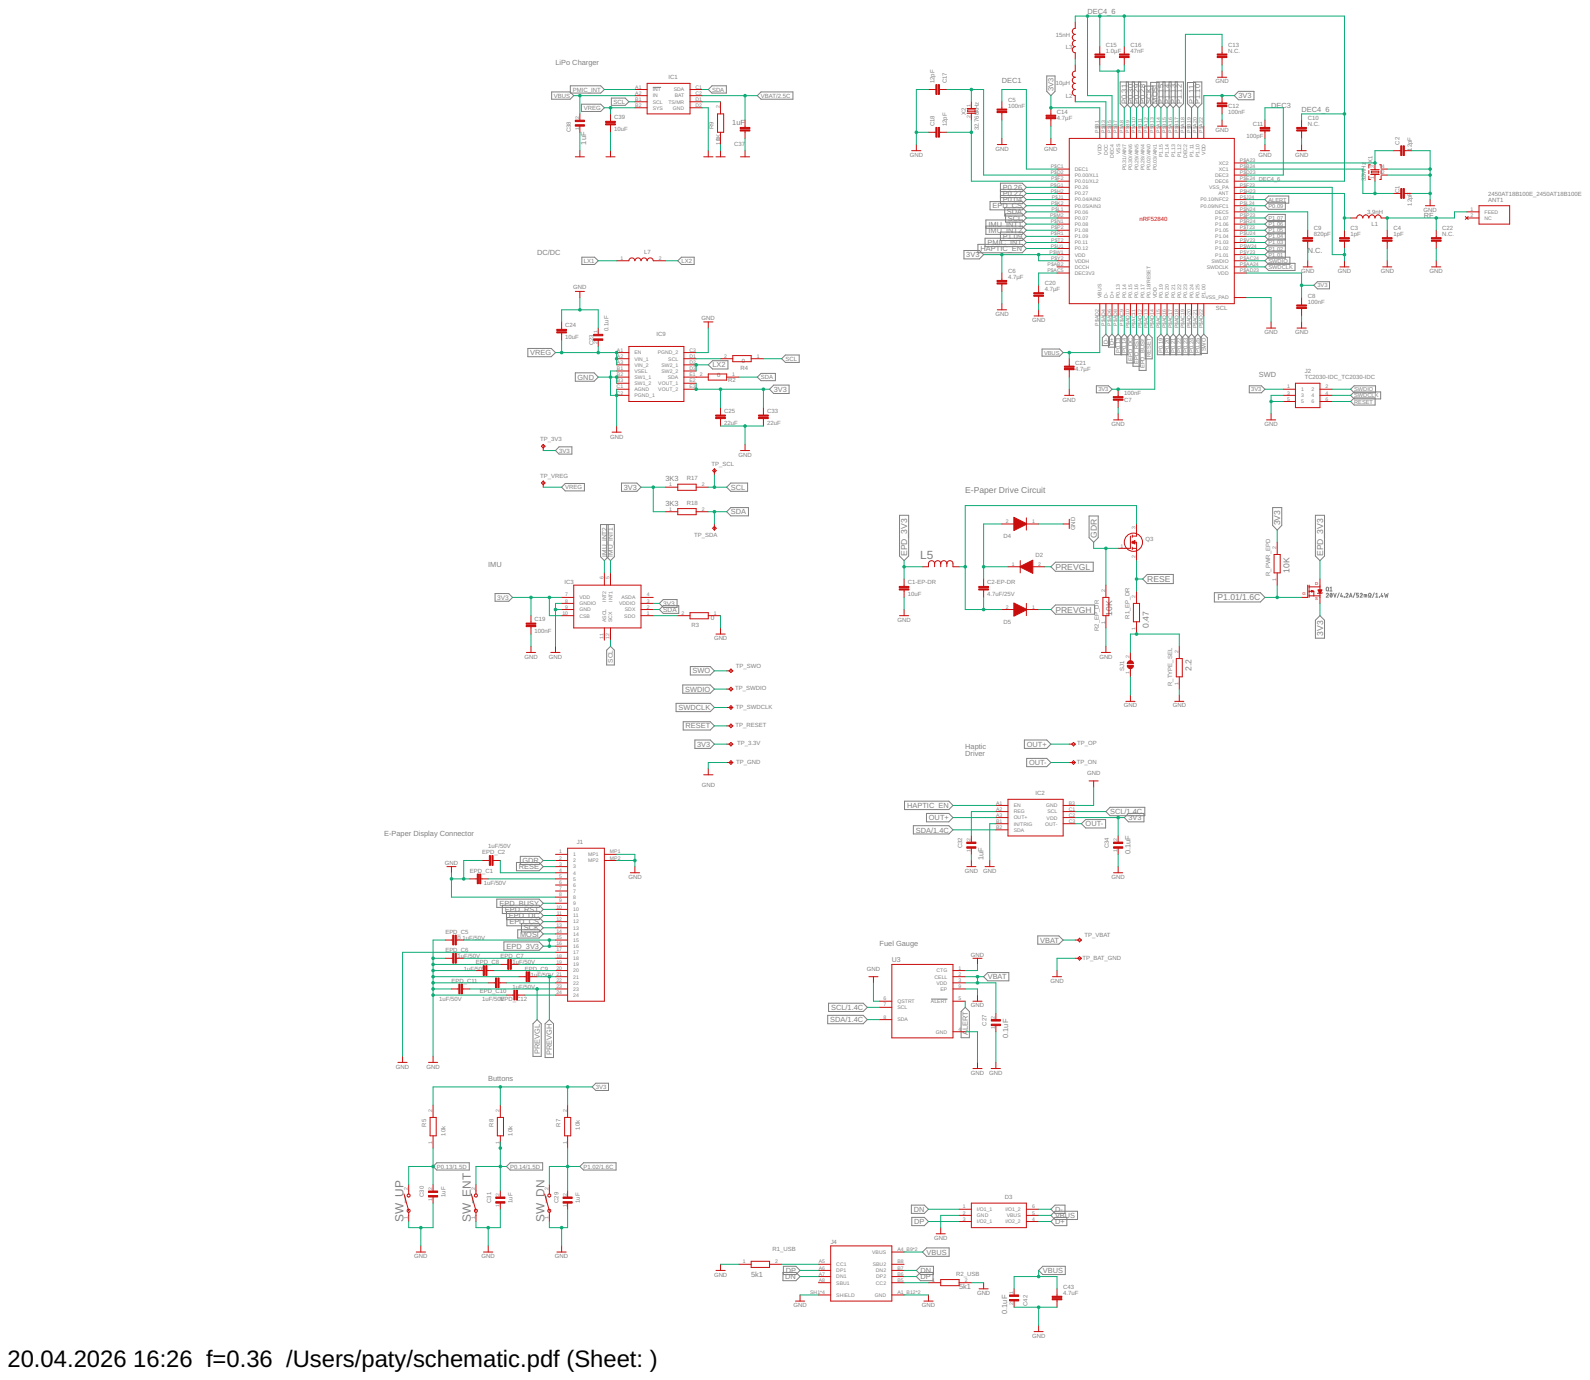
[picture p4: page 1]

20.04.2026 16:26 f=0.36 /Users/paty/schematic.pdf (Sheet: )

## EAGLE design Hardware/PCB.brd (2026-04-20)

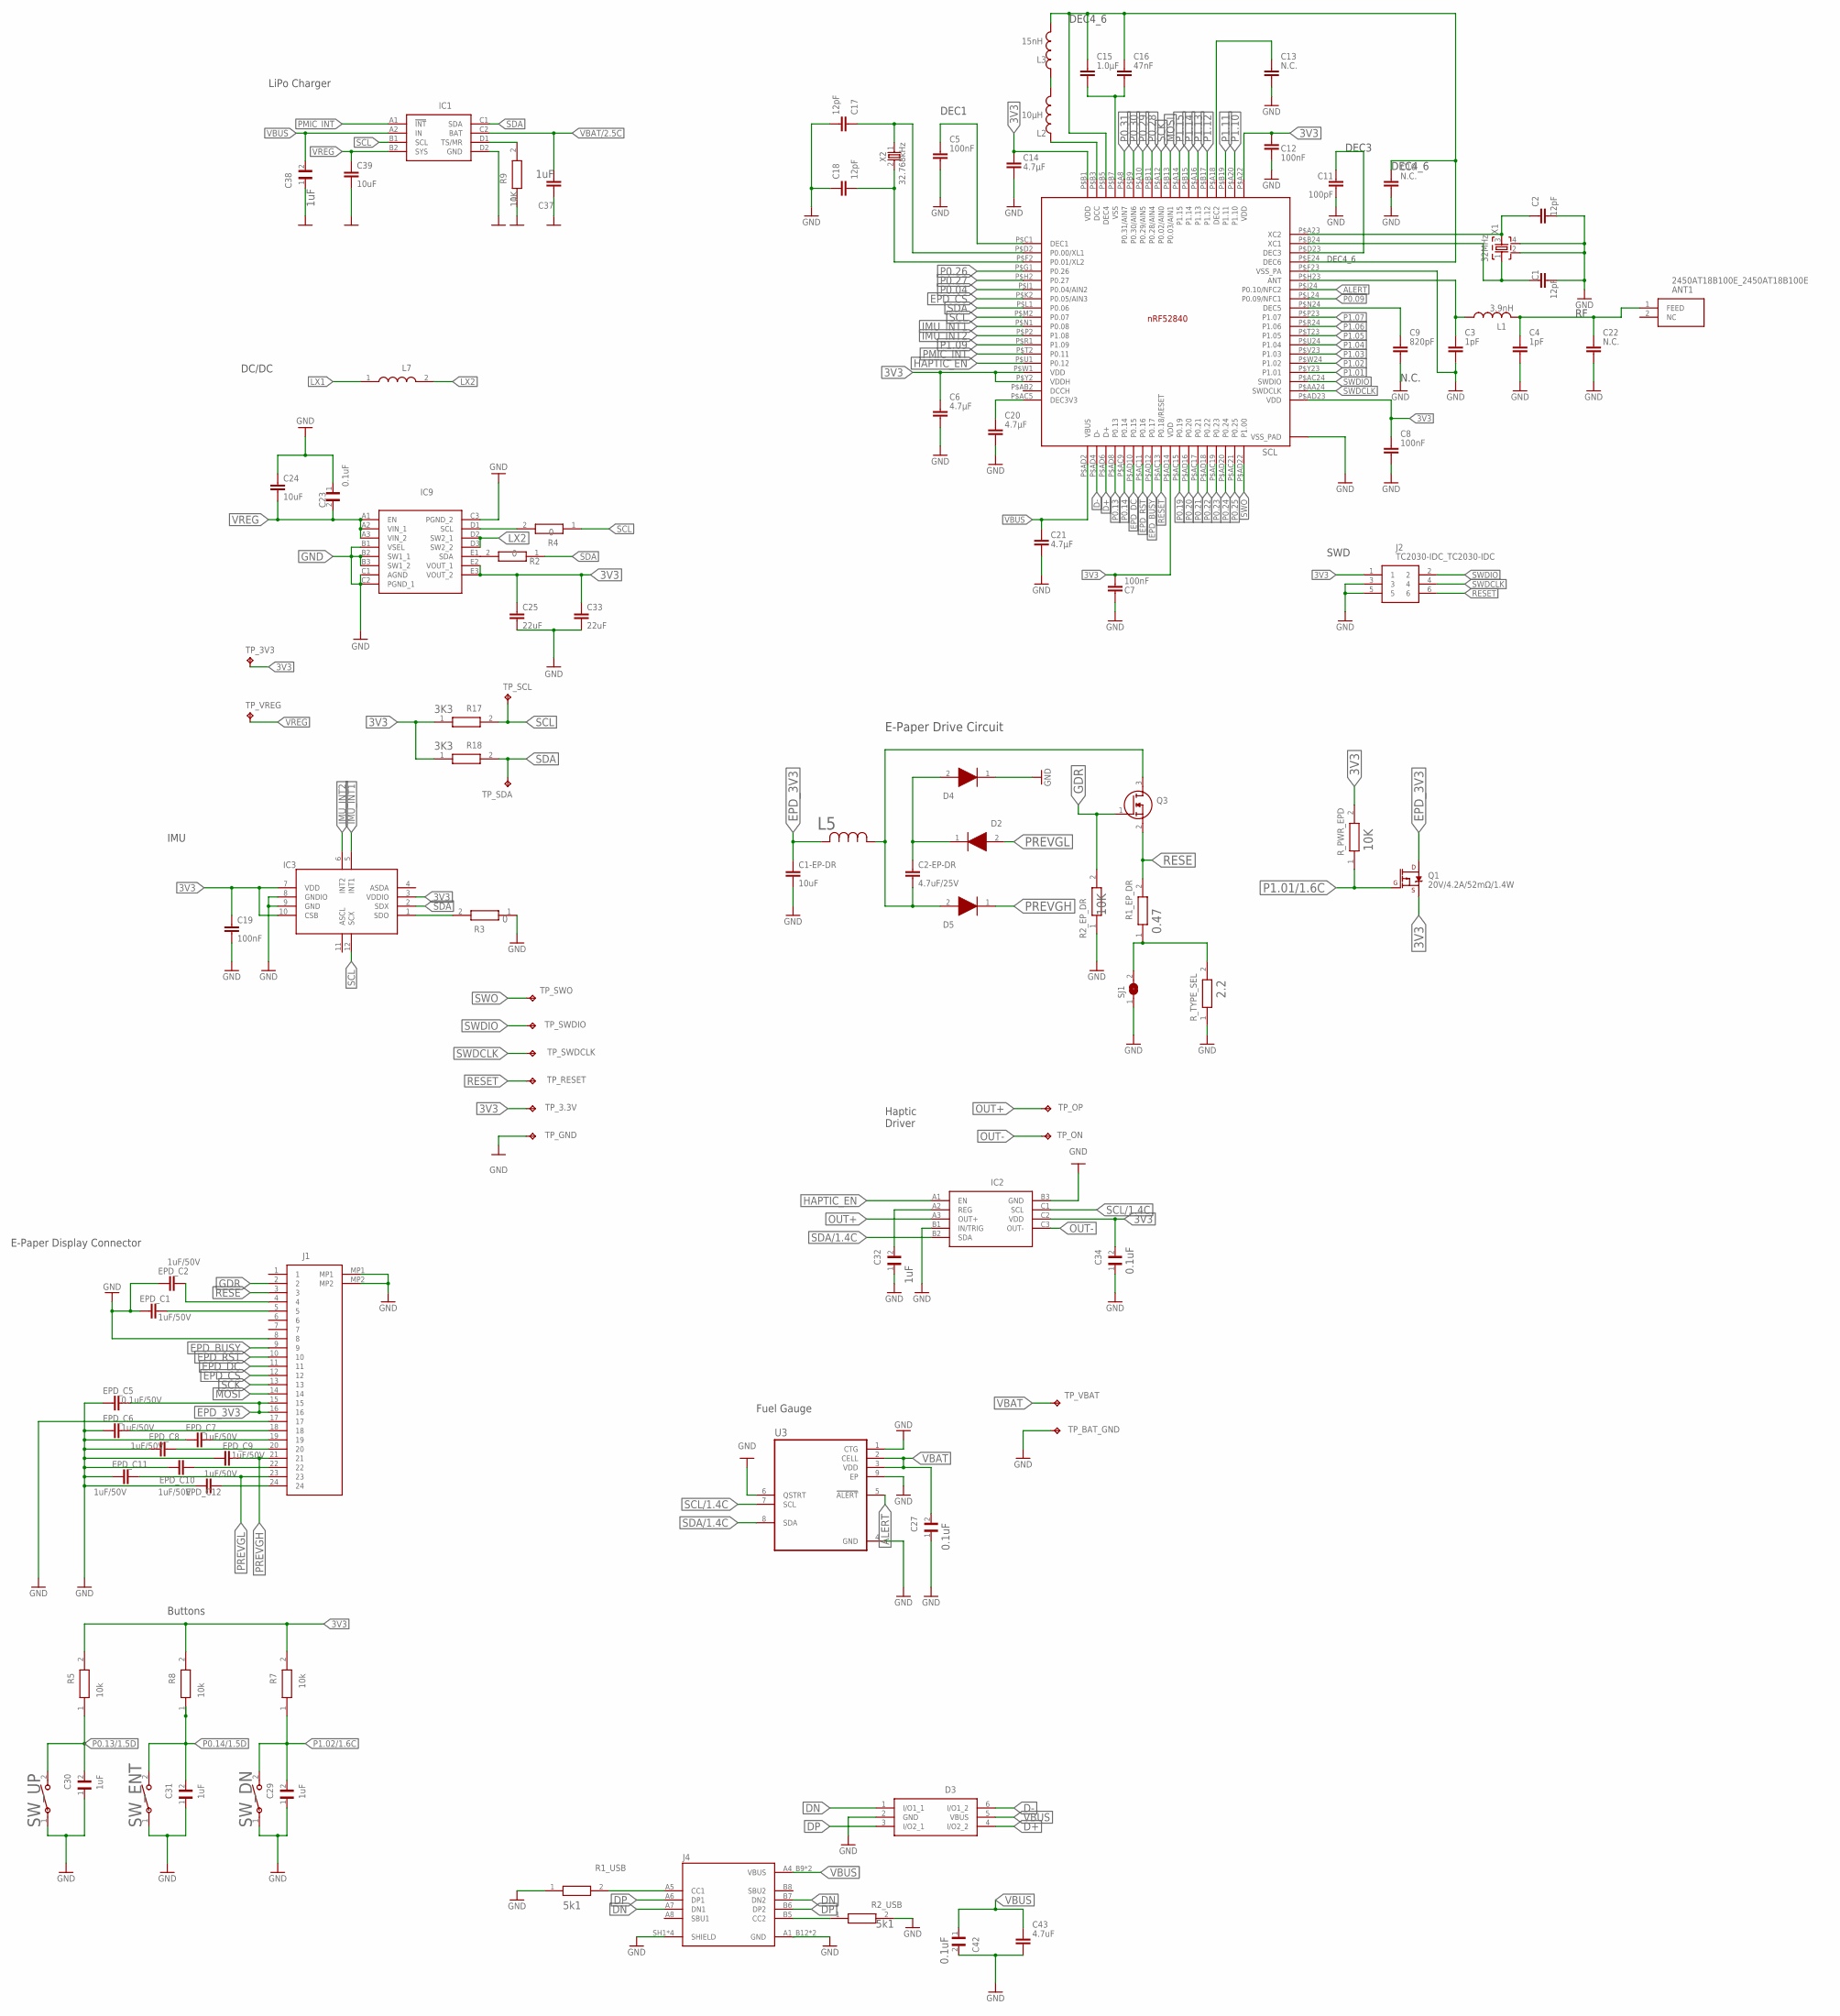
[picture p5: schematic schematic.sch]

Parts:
ANT1: 2450AT18B100E_2450AT18B100E; 2450AT18B100E_ANTC3216X140N
C1, C2, C17, C18: 12pF; NORDIC_NRF_3_RESC0201_L
C1-EP-DR, C24, C39: 10uF; NORDIC_NRF_3_RESC0402_L
C2-EP-DR: 4.7uF/25V; NORDIC_NRF_3_RESC0402_L
C3, C4: 1pF; NORDIC_NRF_3_RESC0201_L
C5, C7, C8, C12, C19: 100nF; NORDIC_NRF_3_RESC0201_L
C6, C14, C20, C21: 4.7µF; NORDIC_NRF_3_RESC0402_L
C9: 820pF; NORDIC_NRF_3_RESC0201_L
C10, C13, C22: N.C.; NORDIC_NRF_3_RESC0201_L
C11: 100pF; NORDIC_NRF_3_RESC0201_L
C15: 1.0µF; NORDIC_NRF_3_RESC0402_L
C16: 47nF; NORDIC_NRF_3_RESC0201_L
C23, C27, C29, C30, C31, C32, C34, C38, C42: GRM011R60J152KE01L_2_GRM011R60J152KE01L; GRM011R60J152KE01L_2_CAPC0201X13N
C25, C33: 22uF; NORDIC_NRF_3_RESC0402_L
C37: NORDIC_NRF_3_CAPACITOR_0402_L; NORDIC_NRF_3_RESC0402_L
C43: 4.7uF; NORDIC_NRF_3_RESC0402_L
D2, D4, D5: ESP32_C6_LIBRARY_5_MBR0530; ESP32_C6_LIBRARY_5_SOD3716X135N
D3: ESP32_C6_LIBRARY_3_USBLC6-2SC6Y; ESP32_C6_LIBRARY_3_SOT95P280X145-6N
EPD_C1, EPD_C2, EPD_C6, EPD_C7, EPD_C8, EPD_C9, EPD_C10, EPD_C11, EPD_C12: 1uF/50V; NORDIC_NRF_3_RESC0402_L
EPD_C5: 0.1uF/50V; NORDIC_NRF_3_RESC0402_L
IC1: BQ25180YBGR_BQ25180YBGR; BQ25180YBGR_BGA8C40P2X4_100X155X50
IC2: DRV2605YZFR_DRV2605YZFR; DRV2605YZFR_BGA9C50P3X3_144X144X62
IC3: BMA423_BMA423
IC9: RT6160AWSC_RT6160AWSC; RT6160AWSC_BGA15C40P3X5_140X230X60
J1: 503480-2400_503480-2400; 503480-2400_5034802400
J2: TC2030-IDC_TC2030-IDC; TC2030-IDC_TC2030IDC
J4: KH-TYPE-C-16P_KH-TYPE-C-16P; KH-TYPE-C-16P_KINGHELM_KH-TYPE-C-16P
L1: 3.9nH; NORDIC_NRF_2_RESC0201_L
L2: 10µH; NORDIC_NRF_2_RESC0201_L
L3: 15nH; NORDIC_NRF_2_RESC0201_L
L5: 10uH; ESP32_C6_LIBRARY_2_IND_4828-WE-TPC_WRE
L7: MLP2016SR47MT0S1_FTC252012SR47MBCA; MLP2016SR47MT0S1_INDC2016X100N
Q1: 20V/4.2A/52mΩ/1.4W; ESP32_C6_LIBRARY_4_ESP32_C6_LIBRARY_4_ESP32_C6_LIBRARY_4_ES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
Q3: ESP32_C6_LIBRARY_6_SI1308EDL-T1-GE3; ESP32_C6_LIBRARY_6_SOT65P210X110-3N
R1_EP_DR, R1_USB, R2_EP_DR, R2_USB, R3: ERA-1AEB3401C_CPF0201D7K68C1; ERA-1AEB3401C_0201
R2, R4, R5, R7, R8, R17, R18: CPF0201D7K68C1_CPF0201D7K68C1; CPF0201D7K68C1_0201
R9: 10k; CPF0201D7K68C1_0201
R_PWR_EPD: ERA-1AEB3401C_CPF0201D7K68C1; ERA-1AEB3401C_0201
R_TYPE_SEL: ERA-1AEB3401C_CPF0201D7K68C1; ERA-1AEB3401C_0201
SCL: NORDIC_NRF_4_NRF52840_QF; NORDIC_NRF_4_AQFN50P700X700X85_HS-74N
SJ1: ESP32_C6_LIBRARY_7_JUMPER_SJ
SW_DN: 2025-10-22_07-23-44_LIBRARY_EVP-AKE31ASW_EVP-AKE3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; 2025-10-22_07-23-44_LIBRARY_SW_EVP-AKE31A_PAN
SW_ENT: 2025-10-22_07-23-44_LIBRARY_EVP-AKE31ASW_EVP-AKE3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; 2025-10-22_07-23-44_LIBRARY_SW_EVP-AKE31A_PAN
SW_UP: 2025-10-22_07-23-44_LIBRARY_EVP-AKE31ASW_EVP-AKE3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; 2025-10-22_07-23-44_LIBRARY_SW_EVP-AKE31A_PAN
TP_3.3V, TP_3V3: HECTOR_WATCH_1_TPTP20R; HECTOR_WATCH_1_TP20R
TP_BAT_GND: HECTOR_WATCH_1_TPTP20R; HECTOR_WATCH_1_TP20R
TP_GND: HECTOR_WATCH_1_TPTP20R; HECTOR_WATCH_1_TP20R
TP_ON: HECTOR_WATCH_1_TPTP20R; HECTOR_WATCH_1_TP20R
TP_OP: HECTOR_WATCH_1_TPTP20R; HECTOR_WATCH_1_TP20R
TP_RESET: HECTOR_WATCH_1_TPTP20R; HECTOR_WATCH_1_TP20R
TP_SCL: HECTOR_WATCH_1_TPTP20R; HECTOR_WATCH_1_TP20R
TP_SDA: HECTOR_WATCH_1_TPTP20R; HECTOR_WATCH_1_TP20R
TP_SWDCLK: HECTOR_WATCH_1_TPTP20R; HECTOR_WATCH_1_TP20R
TP_SWDIO: HECTOR_WATCH_1_TPTP20R; HECTOR_WATCH_1_TP20R
TP_SWO: HECTOR_WATCH_1_TPTP20R; HECTOR_WATCH_1_TP20R
TP_VBAT: HECTOR_WATCH_1_TPTP20R; HECTOR_WATCH_1_TP20R
TP_VREG: HECTOR_WATCH_1_TPTP20R; HECTOR_WATCH_1_TP20R
U3: ESP32_C6_LIBRARY_MAX17048G+T10; ESP32_C6_LIBRARY_SON50P200X200X80-9N
X1: 32MHz; NORDIC_NRF_BT-XTAL_2016_N
X2: 32.768kHz; NORDIC_NRF_1_XTAL_3215_N

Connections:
3V3: C6.1, C7.1, C8.1, C12.1, C14.1, C19.1, C25.1, C33.1, C34.2, IC2.C2 (VDD), IC3.3 (VDDIO), IC3.7 (VDD), IC3.10 (CSB), IC9.E2 (VOUT_1), IC9.E3 (VOUT_2), J2.1, Q1.2 (S), R5.2, R7.2, R8.2, R17.1, R18.1, R_PWR_EPD.2, SCL.P$A22 (VDD), SCL.P$AD14 (VDD), SCL.P$AD23 (VDD), SCL.P$B1 (VDD), SCL.P$W1 (VDD), SCL.P$Y2 (VDDH), TP_3.3V.TP, TP_3V3.TP
ALERT: SCL.P$J24 (P0.10/NFC2), U3.5 (!ALERT)
D+: D3.4 (I/O2_2), SCL.P$AD6 (D+)
D-: D3.6 (I/O1_2), SCL.P$AD4 (D-)
DN: D3.1 (I/O1_1), J4.A7 (DN1), J4.B7 (DN2)
DP: D3.3 (I/O2_1), J4.A6 (DP1), J4.B6 (DP2)
EPD_3V3: C1-EP-DR.1, EPD_C5.2, J1.15, J1.16, L5.2, Q1.3 (D)
EPD_BUSY: J1.9, SCL.P$AD12 (P0.17)
EPD_CS: J1.12, SCL.P$K2 (P0.05/AIN3)
EPD_DC: J1.11, SCL.P$AD10 (P0.15)
EPD_RST: J1.10, SCL.P$AC11 (P0.16)
GDR: J1.2, Q3.1 (G), R2_EP_DR.2
GND: C1.2, C1-EP-DR.2, C2.2, C3.2, C4.2, C5.2, C6.2, C7.2, C8.2, C9.2, C10.2, C11.2, C12.2, C13.2, C14.2, C17.1, C18.1, C19.2, C20.2, C21.2, C22.2, C23.1, C24.1, C25.2, C27.1, C29.1, C30.1, C31.1, C32.1, C33.2, C34.1, C37.1, C38.1, C39.2, C42.2, C43.2, D3.2 (GND), D4.1 (K), EPD_C1.1, EPD_C2.1, EPD_C5.1, EPD_C6.1, EPD_C7.1, EPD_C8.1, EPD_C9.1, EPD_C10.1, EPD_C11.1, EPD_C12.1, IC1.D2 (GND), IC2.B1 (IN/TRIG), IC2.B3 (GND), IC3.8 (GNDIO), IC3.9 (GND), IC9.B1 (VSEL), IC9.B2 (SW1_1), IC9.B3 (SW1_2), IC9.C1 (AGND), IC9.C2 (PGND_1), IC9.C3 (PGND_2), J1.8, J1.17, J1.MP1, J1.MP2, J2.3, J2.5, J4.A1_B12 (GND), J4.A12_B1 (GND), J4.SH1 (SHIELD), J4.SH2 (SHIELD), J4.SH3 (SHIELD), J4.SH4 (SHIELD), R1_USB.1, R2_EP_DR.1, R2_USB.2, R3.1, R9.1, R_TYPE_SEL.1, SCL.P$74 (VSS_PAD), SCL.P$75 (VSS_PAD), SCL.P$76 (VSS_PAD), SCL.P$77 (VSS_PAD), SCL.P$78 (VSS_PAD), SCL.P$79 (VSS_PAD), SCL.P$80 (VSS_PAD), SCL.P$81 (VSS_PAD), SCL.P$82 (VSS_PAD), SCL.P$83 (VSS_PAD), SCL.P$84 (VSS_PAD), SCL.P$85 (VSS_PAD), SCL.P$86 (VSS_PAD), SCL.P$87 (VSS_PAD), SCL.P$88 (VSS_PAD), SCL.P$89 (VSS_PAD), SCL.P$90 (VSS_PAD), SCL.P$F23 (VSS_PA), SJ1.1, SW_DN.1, SW_ENT.1, SW_UP.1, TP_BAT_GND.TP, TP_GND.TP, U3.1 (CTG), U3.4 (GND), U3.6 (QSTRT), U3.9 (EP), X1.2, X1.4
HAPTIC_EN: IC2.A1 (EN), SCL.P$U1 (P0.12)
IMU_INT1: IC3.5 (INT1), SCL.P$N1 (P0.08)
IMU_INT2: IC3.6 (INT2), SCL.P$P2 (P1.08)
LX1: L7.1
LX2: IC9.D2 (SW2_1), IC9.D3 (SW2_2), L7.2
MOSI: J1.14, SCL.P$B13 (P0.03/AIN1)
unnamed: IC9.D1 (SCL), R4.2
unnamed: C20.1, SCL.P$AC5 (DEC3V3)
unnamed: IC1.D1 (TS/MR), R9.2
unnamed: L2.2, L3.1
unnamed: C11.1, SCL.P$D23 (DEC3)
unnamed: IC9.E1 (SDA), R2.2
unnamed: L2.1, SCL.P$B3 (DCC)
unnamed: C10.1, C15.1, C16.1, L3.2, SCL.P$B5 (DEC4), SCL.P$E24 (DEC6)
unnamed: IC3.1 (SDO), R3.2
unnamed: C13.1, SCL.P$A18 (DEC2)
unnamed: EPD_C12.2, J1.24
unnamed: C2.1, SCL.P$A23 (XC2), X1.3
unnamed: C1.1, SCL.P$B24 (XC1), X1.1
unnamed: C9.1, SCL.P$N24 (DEC5)
unnamed: C3.1, L1.1, SCL.P$H23 (ANT)
unnamed: ANT1.1 (FEED), C4.1, C22.1, L1.2
unnamed: C15.2, C16.2, SCL.P$B7 (VSS)
unnamed: C18.2, SCL.P$F2 (P0.01/XL2), X2.2
unnamed: C17.2, SCL.P$D2 (P0.00/XL1), X2.1
unnamed: C5.1, SCL.P$C1 (DEC1)
unnamed: C2-EP-DR.1, D2.1 (K), D4.2 (A)
unnamed: EPD_C1.2, J1.5
unnamed: EPD_C2.2, J1.4
unnamed: J4.B5 (CC2), R2_USB.1
unnamed: R1_EP_DR.1, R_TYPE_SEL.2, SJ1.2
unnamed: C32.2, IC2.A2 (REG)
unnamed: J4.A5 (CC1), R1_USB.2
unnamed: EPD_C6.2, J1.18
unnamed: EPD_C7.2, J1.19
unnamed: EPD_C8.2, J1.20
unnamed: EPD_C10.2, J1.22
NGD: C2-EP-DR.2, D5.2 (A), L5.1, Q3.3 (D)
OUT+: IC2.A3 (OUT+), TP_OP.TP
OUT-: IC2.C3 (OUT-), TP_ON.TP
P0.04: SCL.P$J1 (P0.04/AIN2)
P0.09: SCL.P$L24 (P0.09/NFC1)
P0.13: SCL.P$AD8 (P0.13)
P0.13/1.5D: C30.2, R5.1, SW_UP.2
P0.14: SCL.P$AC9 (P0.14)
P0.14/1.5D: C31.2, R8.1, SW_ENT.2
P0.19: SCL.P$AC15 (P0.19)
P0.20: SCL.P$AD16 (P0.20)
P0.21: SCL.P$AC17 (P0.21)
P0.22: SCL.P$AD18 (P0.22)
P0.23: SCL.P$AC19 (P0.23)
P0.24: SCL.P$AD20 (P0.24)
P0.25: SCL.P$AC21 (P0.25)
P0.26: SCL.P$G1 (P0.26)
P0.27: SCL.P$H2 (P0.27)
P0.28: SCL.P$B11 (P0.28/AIN4)
P0.29: SCL.P$A10 (P0.29/AIN5)
P0.30: SCL.P$B9 (P0.30/AIN6)
P0.31: SCL.P$A8 (P0.31/AIN7)
P1.01: SCL.P$Y23 (P1.01)
P1.01/1.6C: Q1.1 (G), R_PWR_EPD.1
P1.02: SCL.P$W24 (P1.02)
P1.02/1.6C: C29.2, R7.1, SW_DN.2
P1.03: SCL.P$V23 (P1.03)
P1.04: SCL.P$U24 (P1.04)
P1.05: SCL.P$T23 (P1.05)
P1.06: SCL.P$R24 (P1.06)
P1.07: SCL.P$P23 (P1.07)
P1.09: SCL.P$R1 (P1.09)
P1.10: SCL.P$A20 (P1.10)
P1.11: SCL.P$B19 (P1.11)
P1.12: SCL.P$B17 (P1.12)
P1.13: SCL.P$A16 (P1.13)
P1.14: SCL.P$B15 (P1.14)
P1.15: SCL.P$A14 (P1.15)
PMIC_INT: IC1.A1 (!INT), SCL.P$T2 (P0.11)
PREVGH: D5.1 (K), EPD_C9.2, J1.21
PREVGL: D2.2 (A), EPD_C11.2, J1.23
RESE: J1.3, Q3.2 (S), R1_EP_DR.2
RESET: J2.6, SCL.P$AC13 (P0.18/RESET), TP_RESET.TP
SCK: J1.13, SCL.P$A12 (P0.02/AIN0)
SCL: IC1.B1 (SCL), IC3.12 (SCX), R4.1, R17.2, SCL.P$M2 (P0.07), TP_SCL.TP
SCL/1.4C: IC2.C1 (SCL), U3.7 (SCL)
SDA: IC1.C1 (SDA), IC3.2 (SDX), R2.1, R18.2, SCL.P$L1 (P0.06), TP_SDA.TP
SDA/1.4C: IC2.B2 (SDA), U3.8 (SDA)
SWDCLK: J2.4, SCL.P$AA24 (SWDCLK), TP_SWDCLK.TP
SWDIO: J2.2, SCL.P$AC24 (SWDIO), TP_SWDIO.TP
SWO: SCL.P$AD22 (P1.00), TP_SWO.TP
VBAT: C27.2, TP_VBAT.TP, U3.2 (CELL), U3.3 (VDD)
VBAT/2.5C: C37.2, IC1.C2 (BAT)
VBUS: C21.1, C38.2, C42.1, C43.1, D3.5 (VBUS), IC1.A2 (IN), J4.A4_B9 (VBUS), J4.A9_B4 (VBUS), SCL.P$AD2 (VBUS)
VREG: C23.2, C24.2, C39.1, IC1.B2 (SYS), IC9.A1 (EN), IC9.A2 (VIN_1), IC9.A3 (VIN_2), TP_VREG.TP

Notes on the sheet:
LiPo Charger
DC/DC
IMU
DEC1
DEC4_6
DEC3
N.C.
DEC4_6
E-Paper Drive Circuit
SWD
E-Paper Display Connector
Haptic Driver
Fuel Gauge
Buttons

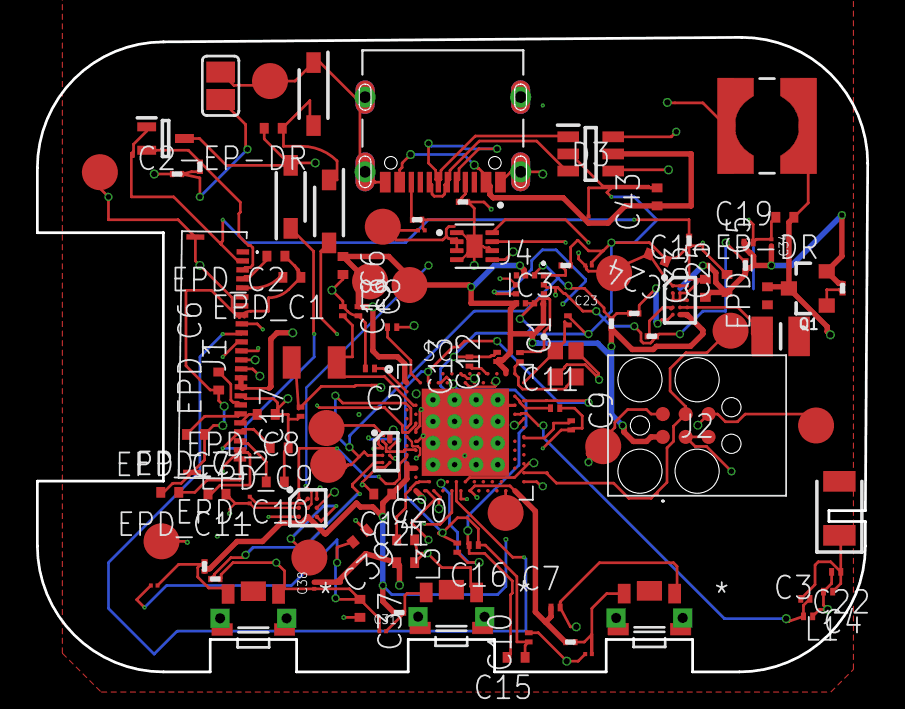
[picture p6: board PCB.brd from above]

Board: 4 copper layers, 46.1 x 35.3 mm, 105 parts (0 on the bottom side), 73 nets.

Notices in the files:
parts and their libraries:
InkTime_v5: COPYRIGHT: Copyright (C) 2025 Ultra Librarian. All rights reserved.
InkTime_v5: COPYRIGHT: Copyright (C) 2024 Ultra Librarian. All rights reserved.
